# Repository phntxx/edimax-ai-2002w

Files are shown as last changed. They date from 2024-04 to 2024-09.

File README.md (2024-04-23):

# Hacking the Edimax Edigreen Home AI-2002W to work with Home Assistant

The Edimax Edigreen Home is a decent air quality monitor.
However, by default, this thing pushes its air quality measurements directly to the cloud,
instead of only broadcasting them on the network.
While this has some convenience advantages, it also has the massive disadvantage of violating
the end-users privacy.

## Hardware

The AI-2002W consists of a Realtek RTL8195A SOC, which provides Wi-Fi connectivity and is the
brains of the operation.
It is then paired with a Plantower PMS5003 Air Quality Sensor, as well as a PCB containing
a MICS-VZ-89TE CO2 sensor and a SHT30-DIS temperature and humidity sensor.

Communication between the main board and the PMS5003 is done via UART,
while communication with the secondary PCB is done via I2C.

The front LEDs are controlled with the help of a TLC59116F 16-Channel I2C LED driver chip.

## Software

The Realtek RTL8195A can be flashed using the Arduino Firmware, as outlined
[here](https://www.amebaiot.com/en/ameba-arduino-getting-started/).

However, during my trials and tribulations, I could not get the I2C communication with
the secondary board to work. My conclusion at this point is that the I2C communication
is wrongly implemented, with no hope that it'll ever be updated to a suitable version, as
the board is already a couple years old at this point.

## Replacing the main board

In the end, I decided to replace the main board with a Wemos D1 mini. This has a number of
benefits, most notably:

- Working I2C implementation
- Decent community support
- Lower power draw (5v microUSB connection vs 12v barrel-jack PSU)

## Reverse-engineering the sensor board

With the help of a multimeter and data sheets for the onboard sensors, I was able to figure out
the connections on the secondary board. With the board laid flat and the connector on the left
side, the connections are as follows:

```
- +3.3V
- SDA
- SCL
- GND
- GND
```

## Wiring up the PMS5003

With the help of the data sheet of the PMS5003, I was able to determine the connections of its
connector (assuming the sensor is laid flat, with the four inlets at the bottom) to be:

```
- +5V
- GND
- SET
- RX
- TX
- RESET
- NC
- NC
```

## Wiring

With this information in hand, the two boards could be connected to the Wemos D1 mini as follows:

- Secondary board:
  - `+3.3V` => `+3.3V` on Wemos
  - `SDA` => `D2` on Wemos
  - `SCL` => `D1` on Wemos
  - `GND` => `GND` on Wemos
- PMS5003:
  - `+5V` => `+5V` on Wemos
  - `GND` => `GND` on Wemos
  - `SET` => `D3` on Wemos
  - `RX` => `D6` on Wemos
  - `TX` => `D7` on Wemos

## Software

I then wrote an Arduino sketch for the Wemos D1 mini that transmits all available
sensor data to a given broker via MQTT.

To install this Arduino sketch on your Wemos D1 mini, first add the ESP8266 series of boards to your Arduino IDE by following the
instructions listed [here](https://github.com/esp8266/Arduino?tab=readme-ov-file#installing-with-boards-manager).

Then, simply clone this repository, open `code.ino` in your Arduino IDE, change the variables from line `11` to line `23` to your
preference and click "Upload".

# References

- [FCC Report: Edimax Edigreen Home AI-2002 - Internal Photos](https://fcc.report/FCC-ID/ndd9520021801/3799812.pdf)
- [MICS-VZ-89TE Datasheet](https://www.sgxsensortech.com/content/uploads/2023/04/DS-0512-MiCS-VZ-89TE.pdf)
- [SHT30-DIS Datasheet](https://www.mouser.com/datasheet/2/682/Sensirion_Humidity_Sensors_SHT3x_Datasheet_digital-971521.pdf)
- [PMS5003 Datasheet](https://www.digikey.jp/htmldatasheets/production/2903006/0/0/1/PMS5003-Series-Manual.pdf)

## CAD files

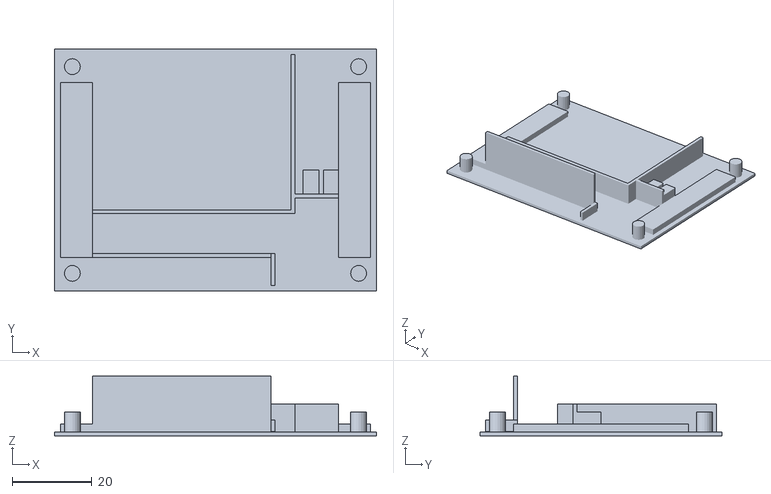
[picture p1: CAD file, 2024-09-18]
case/case-top-pins.stl
81.0 x 61.0 x 15.0

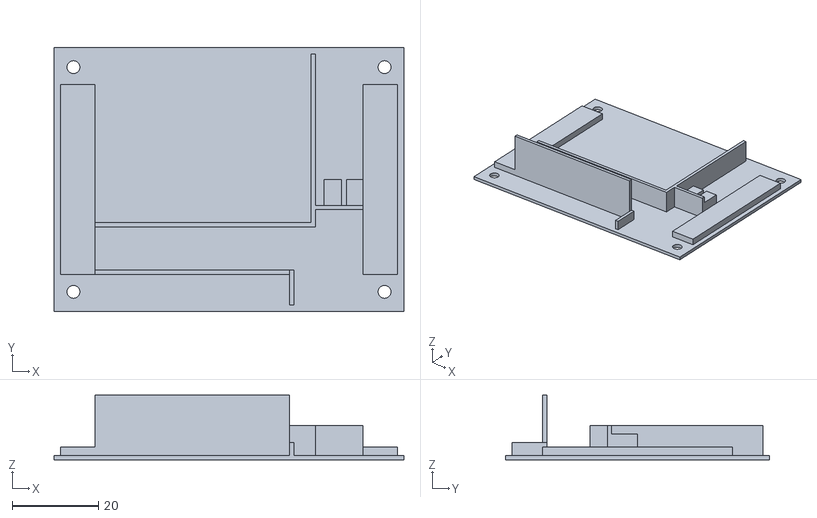
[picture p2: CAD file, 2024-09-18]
case/case-top-holes.stl
81.0 x 61.0 x 15.0

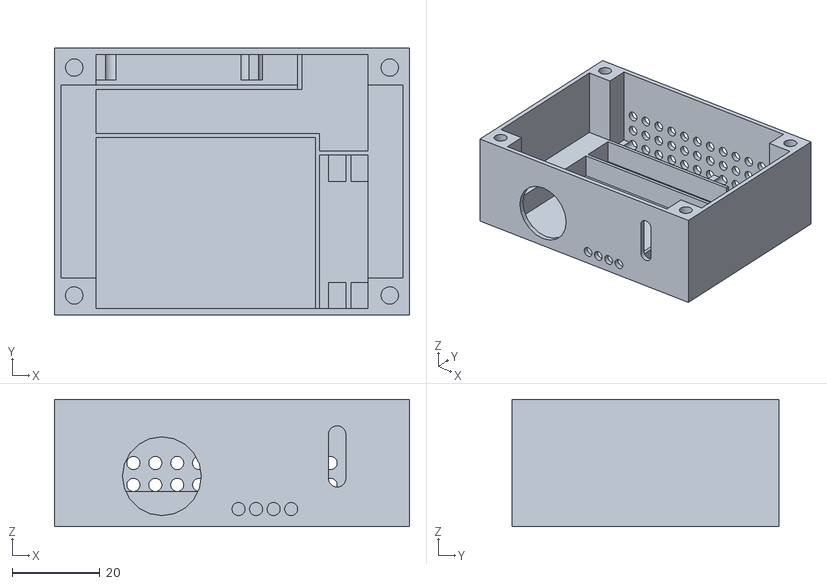
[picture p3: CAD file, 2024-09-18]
case/case-bottom.stl
81.0 x 61.0 x 29.0

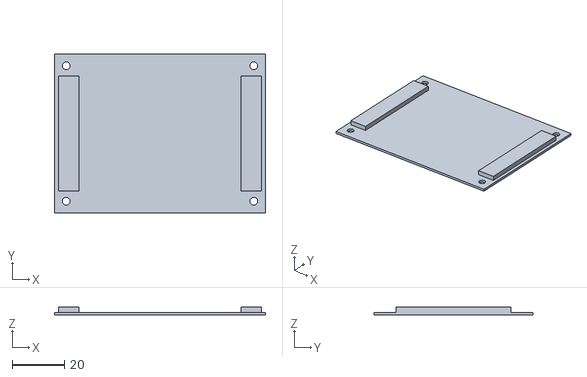
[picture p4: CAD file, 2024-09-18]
case/case-top-simple-holes.stl
81.0 x 61.0 x 3.00

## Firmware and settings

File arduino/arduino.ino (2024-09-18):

#include <ESP8266WiFi.h>
#include <ESP8266mDNS.h>
#include <WiFiUdp.h>
#include <ArduinoOTA.h>
#include <WiFiManager.h>

#include <EEPROM.h>

#include "pms5003.h"
#include "sht30.h"
#include "vz-89te.h"
#include "mqtt.h"

#define MQTT_ID "MQTT_ID"
#define MQTT_BROKER_HOST "MQTT_BROKER_HOST"
#define MQTT_BROKER_PORT 1883
#define MQTT_USER "MQTT_USER"
#define MQTT_PSK "MQTT_PSK"

#define REFRESH_INTERVAL 30000

// BEGIN: Only edit variables here if you know what you're doing

PMS5003 pms5003(13, 12, 9600);

VZ_89TE vz_89te(0x70, &Wire);
SHT30 sht30(0x44, &Wire);

// END: Only edit variables here if you know what you're doing

WiFiManager wifiManager;

WiFiClient wifiClient;
MQTT mqtt(
  MQTT_BROKER_HOST,
  MQTT_BROKER_PORT,
  wifiClient
);

void setup()
{

  // BEGIN: Set up serial connection
  Serial.begin(9600);
  Serial.println("Starting up...");

  // END: Set up serial connection
  // BEGIN: Set up WiFi and MQTT
  wifiManager.setConnectTimeout(10);

  bool result = wifiManager.autoConnect(MQTT_ID);

  if (!result) {
    Serial.println("Connection Failed! Rebooting...");
    ESP.restart();
  }
  
  // END: Set up WiFi and MQTT
  // BEGIN: Set up ArduinoOTA

  ArduinoOTA.setHostname(MQTT_ID);

  ArduinoOTA.onStart([]() {
    String type = (ArduinoOTA.getCommand() == U_FLASH) ? "sketch" : "type";
    Serial.println("Start updating " + type);
  });

  ArduinoOTA.onEnd([]() {
    Serial.println("\nEnd");
  });

  ArduinoOTA.onProgress([](unsigned int progress, unsigned int total) {
    Serial.printf("Progress: %u%%\r", (progress / (total / 100)));
  });

  ArduinoOTA.onError([](ota_error_t error) {
    Serial.printf("Error code: [%u]", error);
  });
  
  // END: Set up ArduinoOTA
  
  // Start up ArduinoOTA
  ArduinoOTA.begin();

  // Start up PMS5003 particulate matter sensor
  pms5003.begin();

  // Start up VZ_89TE CO2/VOC sensor
  Wire.begin();
  vz_89te.begin();

  // Start up SHT30 temperature/humidity sensor
  sht30.begin();
  sht30.setHeater(false);

  // Wait for all systems to properly power up
  delay(5000);
}

void printSensorValues()
{
  Serial.println("--- BEGIN SENSOR INFORMATION ---");

  Serial.println("SHT30: ");
  Serial.printf("Temperature: %fC\n", sht30.temperature());
  Serial.printf("Humidity: %f%%\n", sht30.humidity());
  Serial.println();

  Serial.println("VZ-89TE: ");
  Serial.printf("CO2: %f ppm\n", vz_89te.co2());
  Serial.printf("VOC: %f ppb\n", vz_89te.voc());
  Serial.println();

  Serial.println("PMS5003: ");
  Serial.printf("SP-PM1.0: %i\n", pms5003.sp_pm10());
  Serial.printf("SP-PM2.5: %i\n", pms5003.sp_pm25());
  Serial.printf("SP-PM10: %i\n", pms5003.sp_pm100());
  Serial.printf("AE-PM1.0: %i\n", pms5003.ae_pm10());
  Serial.printf("AE-PM2.5: %i\n", pms5003.ae_pm25());
  Serial.printf("AE-PM10: %i\n", pms5003.ae_pm100());
  Serial.printf("0.3 particles: %i\n", pms5003.p03());
  Serial.printf("0.5 particles: %i\n", pms5003.p05());
  Serial.printf("1.0 particles: %i\n", pms5003.p10());
  Serial.printf("2.5 particles: %i\n", pms5003.p25());
  Serial.printf("5.0 particles: %i\n", pms5003.p50());
  Serial.printf("10.0 particles: %i\n", pms5003.p100());
  Serial.println();

  Serial.println("--- END SENSOR INFORMATION ---");
}

void loop()
{
  String deviceID = String(MQTT_ID);

  if (!mqtt.connected()) {
    mqtt.reconnect(MQTT_ID, MQTT_USER, MQTT_PSK);
  }

  ArduinoOTA.handle();
  mqtt.loop();

  if (sht30.measure())
  {
    mqtt.publish(deviceID + "/sht30/temperature", sht30.temperature());
    mqtt.publish(deviceID + "/sht30/humidity", sht30.humidity());
  }

  if (vz_89te.measure())
  {
    mqtt.publish(deviceID + "/vz-89te/co2", vz_89te.co2());
    mqtt.publish(deviceID + "/vz-89te/voc", vz_89te.voc());
  }

  pms5003.wakeUp();
  if (pms5003.measure())
  {
    mqtt.publish(deviceID + "/pms5003/sp-pm10", pms5003.sp_pm10());
    mqtt.publish(deviceID + "/pms5003/sp-pm25", pms5003.sp_pm25());
    mqtt.publish(deviceID + "/pms5003/sp-pm100", pms5003.sp_pm100());
    mqtt.publish(deviceID + "/pms5003/ae-pm10", pms5003.ae_pm10());
    mqtt.publish(deviceID + "/pms5003/ae-pm25", pms5003.ae_pm25());
    mqtt.publish(deviceID + "/pms5003/ae-pm100", pms5003.ae_pm100());
    mqtt.publish(deviceID + "/pms5003/p03", pms5003.p03());
    mqtt.publish(deviceID + "/pms5003/p05", pms5003.p05());
    mqtt.publish(deviceID + "/pms5003/p10", pms5003.p10());
    mqtt.publish(deviceID + "/pms5003/p25", pms5003.p25());
    mqtt.publish(deviceID + "/pms5003/p50", pms5003.p50());
    mqtt.publish(deviceID + "/pms5003/p100", pms5003.p100());
  }
  pms5003.sleep();

  printSensorValues();
  delay(REFRESH_INTERVAL);
}

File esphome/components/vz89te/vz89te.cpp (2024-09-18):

#include "vz89te.h"
#include "esphome/core/log.h"
#include "esphome/core/hal.h"
#include "esphome/core/helpers.h"

namespace esphome {
namespace vz89te {

static const char *const TAG = "vz89te";

static const uint8_t GET_STATUS_CMD[6] = { 0x0C, 0x00, 0x00, 0x00, 0x00, 0x00 };
static const uint8_t READ_CMD[1] = { 0xE1 };

void VZ89TEComponent::set_values_(const uint8_t *buffer) {
  if (buffer[0] != 0) {
    this->voc_val_ = (buffer[0] - 13) * (1000.0 / 229);
  }

  if (buffer[1] != 0) {
    this->co2_val_ = (buffer[1] - 13) * (1600.0 / 229) + 400;
  }
}

void VZ89TEComponent::setup() {
  if (this->write(nullptr, 0) != i2c::ERROR_OK) {
    ESP_LOGD(TAG, "Communication failed!");
    this->mark_failed();
    return;
  }
}

void VZ89TEComponent::update() {
  uint8_t buffer[7];

  if (this->write(GET_STATUS_CMD, sizeof(GET_STATUS_CMD), false) != i2c::ERROR_OK) {
    this->status_set_warning();
    return;
  }

  if (this->write(READ_CMD, sizeof(READ_CMD), true) != i2c::ERROR_OK) {
    this->status_set_warning();
    return;
  }

  if (this->read(buffer, sizeof(buffer)) != i2c::ERROR_OK) {
    this->status_set_warning();
    return;
  }

  this->set_values_(buffer);

  if (this->co2_ != nullptr) {
    this->co2_->publish_state(this->co2_val_);
  }
  if (this->voc_ != nullptr) {
    this->voc_->publish_state(this->voc_val_);
  }

  this->status_clear_warning();
}

void VZ89TEComponent::publish_nans_() {
  if (this->co2_ != nullptr) {
    this->co2_->publish_state(NAN);
  }
  if (this->voc_ != nullptr) {
    this->voc_->publish_state(NAN);
  }
}

void VZ89TEComponent::dump_config() {

  ESP_LOGCONFIG(TAG, "MiCS VZ-89TE:");
  LOG_I2C_DEVICE(this);
  LOG_UPDATE_INTERVAL(this);

  if (this->is_failed()) {
    ESP_LOGE(TAG, "Communication with MiCS VZ-89TE failed!");
  }
  
  LOG_SENSOR("  ", "CO2", this->co2_);
  LOG_SENSOR("  ", "VOC", this->voc_);
}

}  // namespace vz89te
}  // namespace esphome

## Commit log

2024-04-23 add heater disable
2024-09-18 🚀 Revamp
    [case-bottom.stl, case-top-holes.stl, case-top-pins.stl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]
